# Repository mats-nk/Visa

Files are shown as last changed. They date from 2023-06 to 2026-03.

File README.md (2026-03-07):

# "Visa" Introduction

Visa is old norse for "Show" and thats what this project is about.

## First boot:
 - Activate a AP "LED_MATRIX"
 - Configure WiFi and an MQTT broker

## Second boot and thereafter:
 - Publish to MQTT broker what IP it has got
 - Other configuration is acomplished by publish to specific MQTT topics.

# `tools` folder

Here you can find some python tool for get "weather data to MQTT topics" and "MQTT topics to other MQTT topics" with transformation.

### `weather_mqtt.py` — fetches weather from Open-Meteo or wttr.in and publishes to MQTT
 - Multi-language weather descriptions (10 languages)
 - Configurable fields, units, wind direction format
 - In-place countdown between fetches
 - Script version published as MQTT topic

### `mqtt_bridge.py` — forwards MQTT topics with transforms
 - Normal 1-to-1 forwarding
 - Automatic round-robin when multiple sources share the same destination
 - Transform pipeline: round, scale, offset, suffix, prefix, template, json_field
 - Wildcard subscriptions with dynamic destination topics
 - Script version published as MQTT topic

### `setup.sh` — creates the venv, installs dependencies and runs a smoke test

# MQTT Topic Reference

All topics use the pattern `<hostname>/<suffix>`.

Default hostname is `LED_MATRIX`. Replace with your configured hostname throughout.

All values are persisted to EEPROM unless noted otherwise.

---

## Runtime topics

### `LED_MATRIX/value`
Display a message.
- Long messages (wider than display) scroll continuously.
- Short messages (fits on display) are shown statically.
- A queued message waits until the current scroll pass completes before displaying.
- Supports Swedish characters: `å ä ö Å Ä Ö`
- Supports degree symbol: `°` (UTF-8 `0xC2 0xB0`, auto-transcoded to Latin-1 `0xB0`)

```bash
# Plain text
mosquitto_pub -h <MQTT broker> -t "LED_MATRIX/value" -m "Hello World"

# Swedish characters
mosquitto_pub -h <MQTT broker> -t "LED_MATRIX/value" -m "Hej Sverige åäö"

# Temperature with degree symbol
mosquitto_pub -h <MQTT broker> -t "LED_MATRIX/value" -m "Temp: 22°C"
mosquitto_pub -h <MQTT broker> -t "LED_MATRIX/value" -m "Ute: -5°C  Inne: 21°C"

# Time and date (shell substitution)
mosquitto_pub -h <MQTT broker> -t "LED_MATRIX/value" -m "$(date +'%H:%M')"
mosquitto_pub -h <MQTT broker> -t "LED_MATRIX/value" -m "$(date +'%A %d %B')"

# Combined sensor readout
mosquitto_pub -h <MQTT broker> -t "LED_MATRIX/value" -m "$(date +'%H:%M')  Temp: 22°C  Luftfukt: 45%"

# Clear the display
mosquitto_pub -h <MQTT broker> -t "LED_MATRIX/value" -m ""
```

---

### `LED_MATRIX/speed`
Scroll step delay in milliseconds. Lower = faster scroll.

Range: `10` – `500` ms. Default: `100`

```bash
mosquitto_pub -h <MQTT broker> -t "LED_MATRIX/speed" -m "50"    # fast
mosquitto_pub -h <MQTT broker> -t "LED_MATRIX/speed" -m "100"   # default
mosquitto_pub -h <MQTT broker> -t "LED_MATRIX/speed" -m "200"   # slow
```

---

### `LED_MATRIX/intensity`
Display brightness.
Range: `0` (minimum) – `15` (maximum). Default: `5`

```bash
mosquitto_pub -h <MQTT broker> -t "LED_MATRIX/intensity" -m "0"    # minimum (nearly off)
mosquitto_pub -h <MQTT broker> -t "LED_MATRIX/intensity" -m "5"    # default
mosquitto_pub -h <MQTT broker> -t "LED_MATRIX/intensity" -m "15"   # maximum
```

---

### `LED_MATRIX/state`
Turn display on or off.

`1` = on, `0` = off. Not persisted — resets to on after reboot.

When turned back on the previous message resumes automatically.

```bash
mosquitto_pub -h <MQTT broker> -t "LED_MATRIX/state" -m "0"   # off
mosquitto_pub -h <MQTT broker> -t "LED_MATRIX/state" -m "1"   # on
```

---

### `LED_MATRIX/anim`
Animation mode for scrolling messages.

Default: `0`

| Value | Name | Description |
|---|--- |--- |
| `0` | Scroll left  | Text enters from right, exits left *(default)* |
| `1` | Scroll right | Text enters from left, exits right |
| `2` | Scroll up | Text shifts upward each tick |
| `3` | Scroll down  | Text shifts downward each tick |
| `4` | Flip LR | Static left↔right mirror, redrawn each tick |
| `5` | Flip UD | Static top↔bottom mirror, redrawn each tick |
| `6` | Rotate CW | 90° clockwise rotation applied each tick |
| `7` | Invert | All pixels toggled each tick |
| `8` | Bounce | Ping-pong: scroll left then right alternating  |
| `9` | Scroll left + invert | Scroll left with inverted pixels |
| `10`  | Blink | Whole display blinks at scroll speed |
| `11`  | Wipe in | Columns fill inward from both edges |
| `12`  | Wipe out | Columns clear outward from centre |

```bash
mosquitto_pub -h <MQTT broker> -t "LED_MATRIX/anim" -m "0"    # scroll left (default)
mosquitto_pub -h <MQTT broker> -t "LED_MATRIX/anim" -m "1"    # scroll right
mosquitto_pub -h <MQTT broker> -t "LED_MATRIX/anim" -m "8"    # bounce
mosquitto_pub -h <MQTT broker> -t "LED_MATRIX/anim" -m "10"   # blink
```

---

### `LED_MATRIX/pause`
Hold time in milliseconds after each full message pass before restarting.

`0` = no pause (continuous). Max: `30000` ms. Default: `0`

Behaviour differs by message length:
- **Long message (scrolling):** display is blank during the pause.
- **Short message (static):** message stays visible during the pause, then clears briefly before redisplaying.

```bash
mosquitto_pub -h <MQTT broker> -t "LED_MATRIX/pause" -m "0"      # continuous (default)
mosquitto_pub -h <MQTT broker> -t "LED_MATRIX/pause" -m "2000"   # 2 second pause
mosquitto_pub -h <MQTT broker> -t "LED_MATRIX/pause" -m "5000"   # 5 second pause
mosquitto_pub -h <MQTT broker> -t "LED_MATRIX/pause" -m "10000"  # 10 second pause
```

---

### `LED_MATRIX/align`
Text alignment for short messages that fit within the display width.

Has no effect on scrolling messages. Default: `0`

| Value | Alignment |
|---|---|
| `0` | Left *(default)* |
| `1` | Centre |
| `2` | Right |

```bash
mosquitto_pub -h <MQTT broker> -t "LED_MATRIX/align" -m "0"   # left (default)
mosquitto_pub -h <MQTT broker> -t "LED_MATRIX/align" -m "1"   # centre — good for time "12:45"
mosquitto_pub -h <MQTT broker> -t "LED_MATRIX/align" -m "2"   # right
```

---

## Hardware config topics

Changes to hardware config topics trigger a full matrix reinitialisation without reboot.

The display briefly shows `reconfigured!` then resumes the previous message.

### `LED_MATRIX/config/hwtype`
MAX7219 module hardware type.

Default: `3` (FC16)

| Value | Type |
|---|---|
| `0` | PAROLA_HW |
| `1` | GENERIC_HW |
| `2` | ICSTATION_HW |
| `3` | FC16_HW *(default)* |

```bash
mosquitto_pub -h <MQTT broker> -t "LED_MATRIX/config/hwtype" -m "3"   # FC16 (most common)
mosquitto_pub -h <MQTT broker> -t "LED_MATRIX/config/hwtype" -m "1"   # Generic
```

---

### `LED_MATRIX/config/numdevices`
Number of chained MAX7219 modules.

Range: `1` – `8`. Default: `4`

```bash
mosquitto_pub -h <MQTT broker> -t "LED_MATRIX/config/numdevices" -m "4"   # 4 modules
mosquitto_pub -h <MQTT broker> -t "LED_MATRIX/config/numdevices" -m "8"   # 8 modules
```

---

### `LED_MATRIX/config/clkpin`
GPIO number for SPI CLK.

Default (ESP8266 D1 Mini): `14` (D5)

```bash
mosquitto_pub -h <MQTT broker> -t "LED_MATRIX/config/clkpin" -m "14"
```

---

### `LED_MATRIX/config/datapin`
GPIO number for SPI DATA/MOSI.

Default (ESP8266 D1 Mini): `13` (D7)

```bash
mosquitto_pub -h <MQTT broker> -t "LED_MATRIX/config/datapin" -m "13"
```

---

### `LED_MATRIX/config/cspin`
GPIO number for SPI CS/SS.

Default (ESP8266 D1 Mini): `12` (D6)

```bash
mosquitto_pub -h <MQTT broker> -t "LED_MATRIX/config/cspin" -m "12"
```

---

### `LED_MATRIX/config/auxpin`
GPIO number for auxiliary output (e.g. LDR enable).

Default (ESP8266): `3`

```bash
mosquitto_pub -h <MQTT broker> -t "LED_MATRIX/config/auxpin" -m "3"
```

---

### `LED_MATRIX/config/hbledpin`
GPIO number for heartbeat LED.

Default (ESP8266): `2`

```bash
mosquitto_pub -h <MQTT broker> -t "LED_MATRIX/config/hbledpin" -m "2"
```

---

### `matrix/config/hostname`
Rename the device. **Fixed topic** — always `matrix/config/hostname` regardless of current hostname, so any device can be targeted before its hostname is known.

Max 31 characters. Takes effect immediately — device reconnects to MQTT with the new name.

```bash
mosquitto_pub -h <MQTT broker> -t "matrix/config/hostname" -m "LOBBY"
mosquitto_pub -h <MQTT broker> -t "matrix/config/hostname" -m "RECEPTION"
mosquitto_pub -h <MQTT broker> -t "matrix/config/hostname" -m "LED_MATRIX"   # reset to default
```

---

## Status topic (published by device)

### `LED_MATRIX/config/status`
Published by the device on every MQTT connect and after errors.
Includes firmware version as the first field.

```
fw=2025-03-07.1 hostname=LED_MATRIX mqtt=<MQTT broker>:1883 hwType=3 devices=8 clk=14 data=13 cs=12 aux=3 hbled=2 speed=100 intensity=5 anim=0 pause=0 align=0
```

```bash
# Subscribe to watch status
mosquitto_sub -h <MQTT broker> -t "LED_MATRIX/config/status"

# Trigger a status republish by cycling state
mosquitto_pub -h <MQTT broker> -t "LED_MATRIX/state" -m "1"
```

---

## Active/online topic (published by device)

### `LED_MATRIX/active`
Published as `online` on every MQTT connect. Used by Home Assistant as the availability topic — entities show as unavailable if the device drops off the network.

```bash
mosquitto_sub -h <MQTT broker> -t "LED_MATRIX/active"
```

---

## Practical examples

### Clock display — centred, refreshed every minute
```bash
# Set up display style once
mosquitto_pub -h <MQTT broker> -t "LED_MATRIX/align"   -m "1"     # centre
mosquitto_pub -h <MQTT broker> -t "LED_MATRIX/pause"   -m "0"     # no pause
mosquitto_pub -h <MQTT broker> -t "LED_MATRIX/anim"    -m "0"

# Then update time each minute via cron or Home Assistant automation
mosquitto_pub -h <MQTT broker> -t "LED_MATRIX/value"   -m "$(date +'%H:%M')"
```

### Temperature ticker from Home Assistant
```bash
# Long scrolling message with temperature and humidity
mosquitto_pub -h <MQTT broker> -t "LED_MATRIX/value" -m "Ute: -3°C  Inne: 21°C  Luftfukt: 42%"
mosquitto_pub -h <MQTT broker> -t "LED_MATRIX/speed" -m "80"
mosquitto_pub -h <MQTT broker> -t "LED_MATRIX/pause" -m "3000"
```

### Night mode — dim and slow
```bash
mosquitto_pub -h <MQTT broker> -t "LED_MATRIX/intensity" -m "1"
mosquitto_pub -h <MQTT broker> -t "LED_MATRIX/speed"     -m "150"
```

### Day mode — bright and fast
```bash
mosquitto_pub -h <MQTT broker> -t "LED_MATRIX/intensity" -m "10"
mosquitto_pub -h <MQTT broker> -t "LED_MATRIX/speed"     -m "60"
```

### Turn off at bedtime, on at wake-up
```bash
mosquitto_pub -h <MQTT broker> -t "LED_MATRIX/state" -m "0"   # off — previous message saved
mosquitto_pub -h <MQTT broker> -t "LED_MATRIX/state" -m "1"   # on  — previous message resumes
```

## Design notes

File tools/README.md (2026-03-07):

# Weather MQTT – Documentation

A pair of Python scripts that fetch weather data and forward MQTT topics, driven entirely by YAML configuration files.

---

## Table of Contents

1. [Quick Start](#quick-start)
2. [weather_mqtt.py](#weather_mqttpy)
   - [Requirements](#requirements)
   - [Installation](#installation)
   - [Command-line Usage](#command-line-usage)
   - [Configuration Reference – config.yaml](#configuration-reference--configyaml)
   - [MQTT Topics Published](#mqtt-topics-published)
   - [Weather Fields](#weather-fields)
   - [Units](#units)
   - [Wind Direction Formats](#wind-direction-formats)
   - [Language Support](#language-support)
   - [Running as a Service](#running-as-a-service-weather_mqtt)
3. [mqtt_bridge.py](#mqtt_bridgepy)
   - [Requirements](#requirements-1)
   - [Command-line Usage](#command-line-usage-1)
   - [Configuration Reference – mqtt_bridge_config.yaml](#configuration-reference--mqtt_bridge_configyaml)
   - [Mapping Types](#mapping-types)
   - [Transform Pipeline](#transform-pipeline)
   - [Round-Robin Rotation](#round-robin-rotation)
   - [Wildcard Topics](#wildcard-topics)
   - [Running as a Service](#running-as-a-service-mqtt_bridge)
4. [YAML Tips](#yaml-tips)
5. [Version Numbering](#version-numbering)

---

## Quick Start

```bash
# 1. Create virtual environment and install dependencies
chmod +x setup.sh
./setup.sh

# 2. Edit config.yaml with your location and broker address
# 3. Run
source .venv/bin/activate
python weather_mqtt.py
```

---

## weather_mqtt.py

Fetches current weather conditions (and optionally a short-term forecast) from either **Open-Meteo** or **wttr.in**, and publishes the selected fields to an MQTT broker at a configurable interval.

### Requirements

Python 3.8+ and three packages:

```bash
pip install paho-mqtt requests pyyaml
```

### Installation

```bash
./setup.sh          # creates .venv, installs packages, runs a smoke test
```

Or manually:

```bash
python -m venv .venv
source .venv/bin/activate
pip install paho-mqtt requests pyyaml
```

### Command-line Usage

```
python weather_mqtt.py [options]

Options:
  --config FILE   Path to YAML config file  (default: config.yaml)
  --once          Fetch once and exit – ignores the interval setting
  --dry-run       Print payloads to stdout without connecting to MQTT
```

Examples:

```bash
# Test without touching the broker
python weather_mqtt.py --dry-run --once

# Use a custom config file
python weather_mqtt.py --config my_weather.yaml

# Run continuously (default)
python weather_mqtt.py
```

---

### Configuration Reference – config.yaml

#### `mqtt` section

| Key | Default | Description |
|-----|---|---|
| `broker` | `localhost` | Hostname or IP of your MQTT broker |
| `port` | `1883` | Port – use `8883` for TLS |
| `username` | `""` | Leave empty if no authentication required |
| `password` | `""` | Leave empty if no authentication required |
| `client_id` | `weather_publisher` | MQTT client identifier |
| `tls` | `false` | Enable TLS/SSL |
| `ca_cert` | *(unset)* | Path to CA certificate file (TLS only) |
| `base_topic` | `weather` | Root topic prefix |
| `topic_per_field` | `true` | `true` = one sub-topic per field; `false` = single JSON payload |
| `json_topic` | `weather/all` | Topic used when `topic_per_field` is `false` |
| `retain` | `true` | Set the MQTT retain flag on published messages |
| `qos` | `1` | MQTT QoS level – `0`, `1`, or `2` |

#### `weather` section

| Key | Default | Description |
|-----|---|---|
| `service` | `open-meteo` | Weather data source: `open-meteo` or `wttr.in` |
| `latitude` | — | Decimal degrees latitude |
| `longitude` | — | Decimal degrees longitude |
| `location_name` | — | Human-readable name – used by wttr.in as the lookup string |
| `interval` | `900` | Seconds between fetches (900 = every 15 minutes) |
| `language` | `en` | Language for weather descriptions – see [Language Support](#language-support) |

#### `weather.units` section

| Key | Default | Options | Description |
|-----|---|---|---|
| `temperature` | `celsius` | `celsius` / `fahrenheit` | Temperature unit |
| `wind_speed` | `ms` | `ms` / `kmh` / `mph` / `knots` | Wind speed unit |
| `wind_direction` | `16-compass` | `degrees` / `16-compass` / `12-compass` | Wind direction format |
| `precipitation` | `mm` | `mm` / `inch` | Precipitation unit |
| `timezone` | `auto` | Any IANA tz string | Open-Meteo only – `auto` uses the location's timezone |

#### `weather.fields` section

Each field can be set to `true` (publish) or `false` (skip).

| Field | Description | Service |
|---|---|---|
| `temperature` | Current temperature | Both |
| `feels_like` | Apparent / feels-like temperature | Both |
| `humidity` | Relative humidity (%) | Both |
| `precipitation` | Precipitation last hour | Both |
| `rain` | Rain component | open-meteo |
| `wind_speed` | Wind speed | Both |
| `wind_direction` | Wind direction (format per `units.wind_direction`) | Both |
| `wind_gusts` | Wind gust speed | Both |
| `cloud_cover` | Cloud cover (%) | Both |
| `visibility` | Visibility (metres) | open-meteo |
| `surface_pressure` | Atmospheric pressure (hPa) | Both |
| `weather_code` | WMO numeric weather code | Both |
| `weather_description` | Human-readable description of the weather code | Both |
| `is_day` | `1` = daytime, `0` = night | open-meteo |
| `forecast_enabled` | Enable hourly forecast | open-meteo |
| `forecast_hours` | How many hours of forecast to include | open-meteo |
| `forecast_temperature_max` | Max temperature per forecast hour | open-meteo |
| `forecast_temperature_min` | Min temperature per forecast hour | open-meteo |
| `forecast_precipitation_sum` | Precipitation sum per forecast hour | open-meteo |
| `forecast_wind_speed_max` | Max wind speed per forecast hour | open-meteo |
| `forecast_weather_code` | Weather code per forecast hour | open-meteo |

#### `logging` section

| Key | Default | Description |
|-----|---|---|
| `level` | `INFO` | Log level: `DEBUG` / `INFO` / `WARNING` / `ERROR` |
| `log_to_file` | `false` | Also write log output to a file |
| `log_file` | `weather_mqtt.log` | Log file path (only used when `log_to_file: true`) |

---

### MQTT Topics Published

With `base_topic: weather` and `topic_per_field: true`:

```
weather/version               → 2026-03-07.1
weather/temperature           → 21.4
weather/feels_like            → 19.8
weather/humidity              → 62
weather/wind_speed            → 4.2
weather/wind_direction        → WSW
weather/wind_gusts            → 7.1
weather/precipitation         → 0.0
weather/cloud_cover           → 45
weather/surface_pressure      → 1013.2
weather/weather_code          → 2
weather/weather_description   → Halvklart
weather/timestamp             → 2026-03-07T20:33:00+00:00
weather/source                → open-meteo
```

With `topic_per_field: false`, all fields are published as a single JSON object to `weather/all`.

---

### Weather Fields

All numeric values are plain strings (no unit suffix) so downstream consumers can parse them as numbers directly. Use `mqtt_bridge.py` with a `suffix` transform if you need a unit appended.

---

### Units

**Temperature:** `celsius` or `fahrenheit`

**Wind speed:**

| Value | Unit |
|---|---|
| `ms` | metres per second (default) |
| `kmh` | kilometres per hour |
| `mph` | miles per hour |
| `knots` | knots |

**Precipitation:** `mm` or `inch`

---

### Wind Direction Formats

| Value | Example output | Sector size |
|---|---|---|
| `degrees` | `247` | raw 0–360° float |
| `16-compass` | `WSW` | 22.5° per sector |
| `12-compass` | `W` | 30° per sector |

---

### Language Support

Set `language` under the `weather` key. Descriptions fall back to English for any untranslated code.

| Code | Language |
|---|---|
| `en` | English |
| `sv` | Swedish |
| `de` | German |
| `fr` | French |
| `nl` | Dutch |
| `es` | Spanish |
| `no` | Norwegian |
| `fi` | Finnish |
| `da` | Danish |
| `pl` | Polish |

To add a language, add a new key to `_WMO_TRANSLATIONS` in `weather_mqtt.py`. The key is the ISO 639-1 code in lower-case.

---

### Running as a Service (weather_mqtt)

```ini
# /etc/systemd/system/weather_mqtt.service
[Unit]
Description=Weather MQTT Publisher
After=network-online.target

[Service]
ExecStart=/opt/weather/. .venv/bin/activate && python weather_mqtt.py
WorkingDirectory=/opt/weather
Restart=on-failure
RestartSec=30

[Install]
WantedBy=multi-user.target
```

```bash
sudo systemctl enable --now weather_mqtt
```

---

## mqtt_bridge.py

Subscribes to MQTT topics on a source broker and republishes them to a destination broker (which can be the same broker). Supports value transforms, wildcard subscriptions, and automatic round-robin rotation when multiple sources share the same destination topic.

### Requirements

Python 3.8+ and two packages:

```bash
pip install paho-mqtt pyyaml
```

### Command-line Usage

```
python mqtt_bridge.py [options]

Options:
  --config FILE   Path to YAML config file  (default: mqtt_bridge_config.yaml)
  --dry-run       Log all forwards without publishing to destination
  --list          Print active mappings and exit
```

Examples:

```bash
# See all active mappings
python mqtt_bridge.py --list

# Test without publishing anything
python mqtt_bridge.py --dry-run

# Use a custom config
python mqtt_bridge.py --config home_bridge.yaml
```

Sample `--list` output:

```
mqtt_bridge.py  v2026-03-07.1
────────────────────────────────────────────────────────────
  Active mappings  (2):
    weather/temperature             →  house/outside/temperature
    weather/humidity                →  house/outside/humidity

  Active round-robin group  (1):
    → LED_MATRIX/value
      [1] weather/temperature    [round:0 → suffix: °C → prefix:Ute:  ]
      [2] weather/wind_speed     [round:1 → suffix: m/s → prefix:Blåst:  ]
      [3] weather/humidity       [round:2 → suffix: % → prefix:Fukt:  ]

  Disabled mappings  (3):
    ...
```

---

### Configuration Reference – mqtt_bridge_config.yaml

#### `source` section

| Key | Default | Description |
|-----|---|---|
| `broker` | `localhost` | Source broker hostname or IP |
| `port` | `1883` | Source broker port |
| `username` | `""` | Authentication username |
| `password` | `""` | Authentication password |
| `client_id` | `mqtt_bridge_source` | MQTT client identifier |
| `tls` | `false` | Enable TLS |
| `ca_cert` | *(unset)* | CA certificate path (TLS only) |

#### `destination` section

Same keys as `source`, plus:

| Key | Default | Description |
|-----|---|---|
| `client_id` | `mqtt_bridge_destination` | MQTT client identifier |
| `retain` | `true` | Global retain flag for published messages |
| `qos` | `1` | Global QoS for published messages |

> Source and destination can point to the same broker — topic names must then differ to avoid loops.

#### `bridge` section

| Key | Default | Description |
|-----|---|---|
| `heartbeat_interval` | `60` | Seconds between heartbeats and round-robin advances. Set to `0` to disable. |
| `version_topic` | `bridge/version` | Topic where the script version is published on startup and each heartbeat |

#### `logging` section

| Key | Default | Description |
|-----|---|---|
| `level` | `INFO` | `DEBUG` / `INFO` / `WARNING` / `ERROR` |
| `log_to_file` | `false` | Write log output to a file |
| `log_file` | `mqtt_bridge.log` | Log file path |

---

### Mapping Types

#### Normal mapping

Forwards every received message immediately.

```yaml
mappings:
  - from: "weather/temperature"
    to:   "house/outside/temperature"
    enabled: true
```

| Key | Default | Description |
|-----|---|---|
| `from` | — | Source topic to subscribe to |
| `to` | — | Destination topic to publish to |
| `enabled` | `true` | Set `false` to disable without deleting |
| `retain` | *(global)* | Override global retain for this mapping |
| `qos` | *(global)* | Override global QoS for this mapping |
| `transform` | *(none)* | Single transform string or list of steps |
| `round_robin` | `false` | Force round-robin even with a unique destination |

#### Round-robin mapping

When two or more enabled mappings share the same `to` topic, they are **automatically grouped** into a round-robin. On each heartbeat, only one source is published to the shared destination, rotating through the list in order.

```yaml
mappings:
  - from: "weather/temperature"
    to:   "LED_MATRIX/value"
    transform:
      - "round:0"
      - "suffix: °C"
      - 'prefix:Ute:  '

  - from: "weather/wind_speed"
    to:   "LED_MATRIX/value"
    transform:
      - "round:1"
      - "suffix: m/s"
      - 'prefix:Blåst:  '

  - from: "weather/humidity"
    to:   "LED_MATRIX/value"
    transform:
      - "round:0"
      - "suffix: %"
      - 'prefix:Fukt:  '
```

Rotation sequence per heartbeat:

```
Heartbeat 1 → weather/temperature → LED_MATRIX/value : Ute:  21 °C
Heartbeat 2 → weather/wind_speed  → LED_MATRIX/value : Blåst:  3.2 m/s
Heartbeat 3 → weather/humidity    → LED_MATRIX/value : Fukt:  62 %
Heartbeat 4 → weather/temperature → LED_MATRIX/value : Ute:  21 °C  (wraps)
```

> The `heartbeat_interval` in the `bridge` section controls how quickly the rotation advances.

---

### Transform Pipeline

A `transform` can be a **single string** or a **YAML list** applied left-to-right:

```yaml
# Single step
transform: "round:1"

# Pipeline – output of each step feeds into the next
transform:
  - "round:1"
  - "suffix: °C"
  - 'prefix:Temp:  '
```

#### Available transforms

| Transform | Example | Input | Output |
|---|---|---|---|
| `passthrough` | `passthrough` | `21.357` | `21.357` |
| `round:N` | `round:1` | `21.357` | `21.4` |
| `scale:F` | `scale:0.1` | `213.57` | `21.357` |
| `offset:N` | `offset:-273.15` | `294.15` | `21.0` |
| `upper` | `upper` | `partly cloudy` | `PARTLY CLOUDY` |
| `lower` | `lower` | `PARTLY CLOUDY` | `partly cloudy` |
| `suffix:STR` | `suffix: °C` | `21.4` | `21.4 °C` |
| `prefix:STR` | `'prefix:Ute:  '` | `21.4` | `Ute:  21.4` |
| `json_field:KEY` | `json_field:temperature` | `{"temperature":21.4}` | `21.4` |
| `template:STR` | `template:Temp is {value}` | `21.4` | `Temp is 21.4` |

> **YAML tip:** When your `prefix` or `suffix` ends with spaces, always use **single quotes** to prevent YAML from stripping trailing whitespace:
> ```yaml
> transform: 'prefix:Ute:  '   # ✓ spaces preserved
> transform: "prefix:Ute:  "   # ✗ trailing spaces may be stripped
> ```

---

### Wildcard Topics

MQTT wildcards `+` (single level) and `#` (multi-level) are supported in `from`.
The matched topic segments can be used in the `to` pattern:

| Placeholder | Meaning |
|---|---|
| `{topic}` | Full source topic string |
| `{0}`, `{1}`, … | Individual topic levels (0-indexed) |

```yaml
# Forward every sensor's temperature to an archive topic
- from: "sensors/+/temperature"
  to:   "archive/{1}/temp"
  # sensors/kitchen/temperature → archive/kitchen/temp
  # sensors/garden/temperature  → archive/garden/temp

# Archive everything under weather/
- from: "weather/#"
  to:   "archive/{1}"
  # weather/temperature → archive/temperature
  # weather/humidity    → archive/humidity
```

---

### Running as a Service (mqtt_bridge)

```ini
# /etc/systemd/system/mqtt_bridge.service
[Unit]
Description=MQTT Topic Bridge
After=network-online.target

[Service]
ExecStart=/opt/weather/.venv/bin/python /opt/weather/mqtt_bridge.py
WorkingDirectory=/opt/weather
Restart=on-failure
RestartSec=15

[Install]
WantedBy=multi-user.target
```

```bash
sudo systemctl enable --now mqtt_bridge
```

---

## YAML Tips

**Indentation** — YAML uses spaces, never tabs. All items in the same list must align exactly:

```yaml
# ✓ correct – all dashes at the same column
transform:
  - "round:1"
  - "suffix: °C"

# ✗ wrong – mixed indentation causes a parser error
transform:
      - "round:1"
     - "suffix: °C"
```

**One key per entry** — duplicate keys are silently overwritten:

```yaml
# ✗ wrong – second transform silently replaces the first
- from: "weather/temperature"
  transform: "round:1"
  transform: "suffix: °C"

# ✓ correct – use a list
- from: "weather/temperature"
  transform:
    - "round:1"
    - "suffix: °C"
```

**Trailing spaces** — always use single quotes when your value ends with spaces:

```yaml
transform: 'prefix:Ute:  '    # ✓ spaces kept
transform: "prefix:Ute:  "    # ✗ spaces may be stripped
```

**`mappings:` must be a top-level key** — do not nest it inside `bridge:` or any other section:

```yaml
bridge:
  heartbeat_interval: 10

mappings:           # ✓ top-level
  - from: "..."
```

---

## Version Numbering

Both scripts use the format `YYYY-MM-DD.N` where `N` is a sequence number starting at 1 for that date.

```python
__VERSION__ = "2026-03-07.1"
```

The version is published as an MQTT topic on startup (and on every heartbeat for `mqtt_bridge.py`):

| Script | Topic |
|---|---|
| `weather_mqtt.py` | `{base_topic}/version` e.g. `weather/version` |
| `mqtt_bridge.py` | configured by `bridge.version_topic` e.g. `bridge/version` |

To bump the version after making changes, edit the `__VERSION__` line near the top of the relevant script.

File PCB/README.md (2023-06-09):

# MAX7219 4x8x8 matrix module

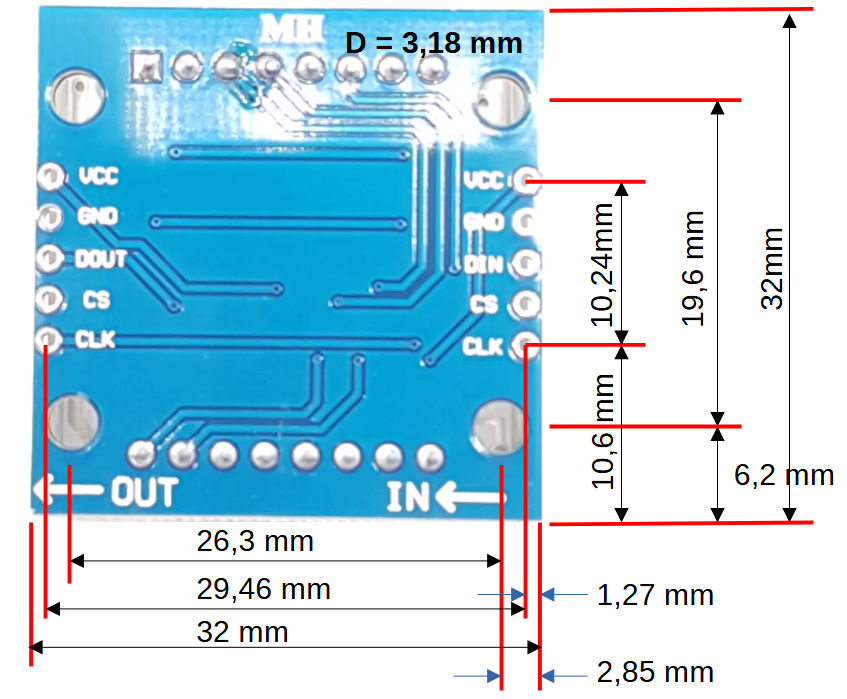
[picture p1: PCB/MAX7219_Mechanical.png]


# ESP8266 

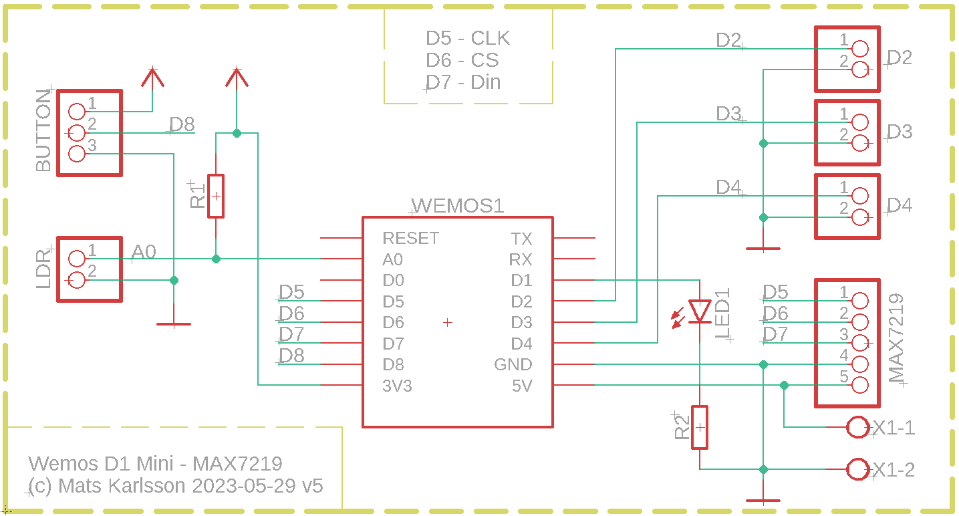
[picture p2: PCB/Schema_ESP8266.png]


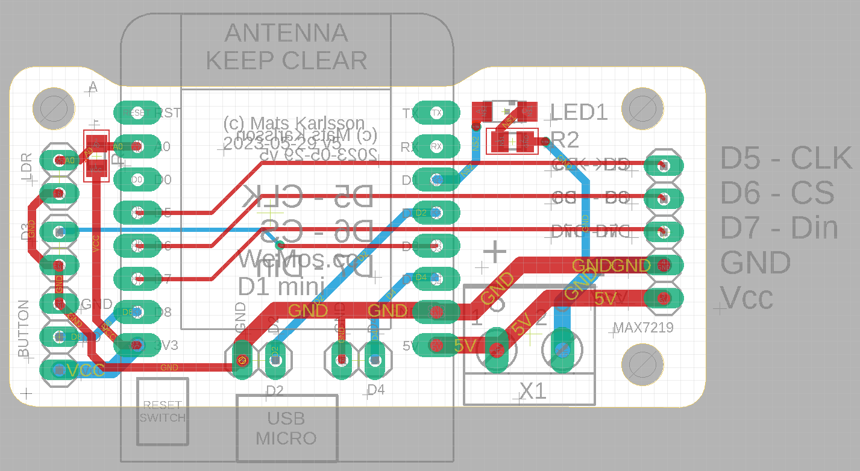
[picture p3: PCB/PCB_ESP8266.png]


# ESP32

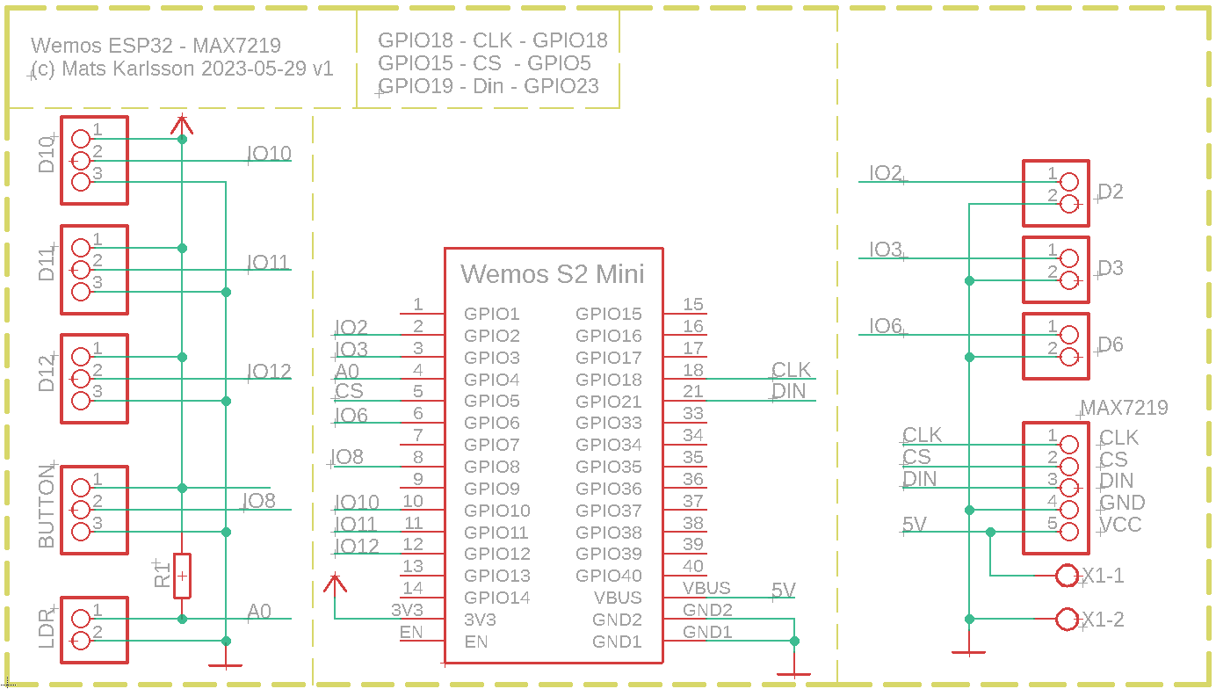
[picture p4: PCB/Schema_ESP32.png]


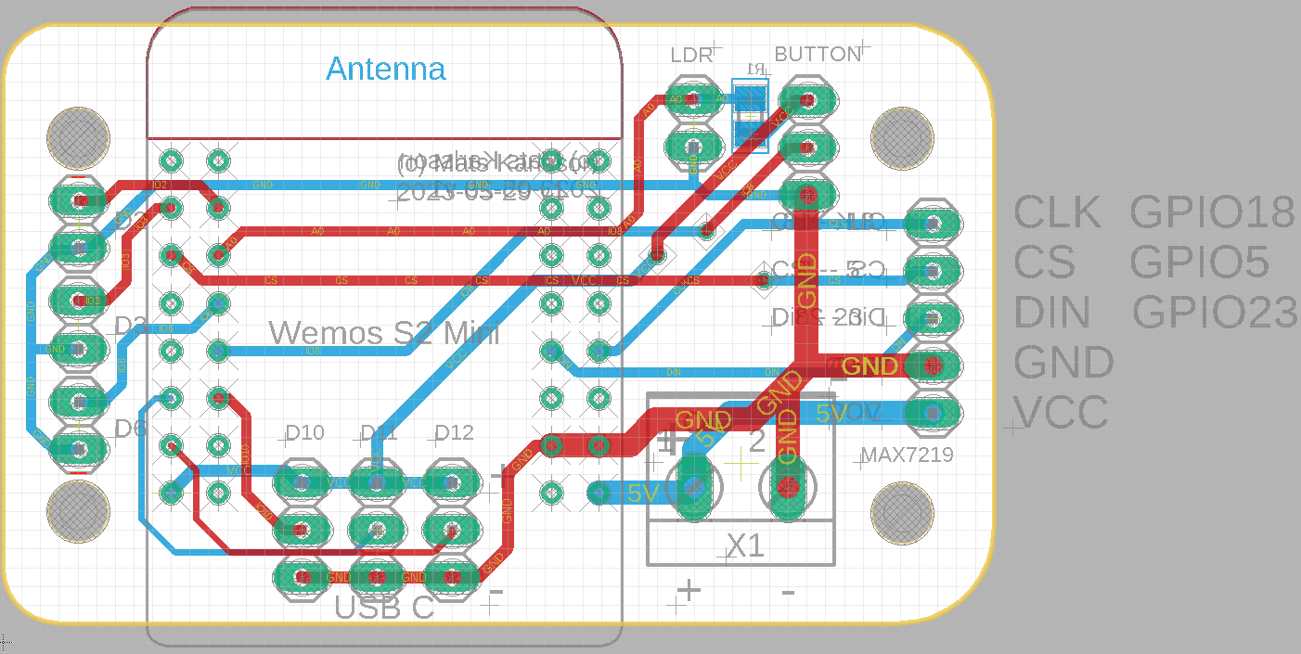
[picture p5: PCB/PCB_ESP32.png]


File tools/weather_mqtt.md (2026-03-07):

# weather_mqtt – Weather → MQTT Publisher

Fetch current weather (and optionally a short-term forecast) from
**Open-Meteo** or **wttr.in** and publish the selected fields to an MQTT
broker. Everything is driven by a single `config.yaml` file.

---

## Files

| File | Purpose |
|---|---|
| `weather_mqtt.py` | Main script |
| `config.yaml` | All configuration (edit this) |

---

## Requirements

Python 3.8 + and three pip packages:

```bash
pip install paho-mqtt requests pyyaml
```

---

## Quick start

1. **Edit `config.yaml`** – set your broker address, location, and the fields
   you want.
2. **Test without MQTT:**
   ```bash
   python weather_mqtt.py --dry-run --once
   ```
3. **Run once for real:**
   ```bash
   python weather_mqtt.py --once
   ```
4. **Run continuously** (publishes every `interval` seconds):
   ```bash
   python weather_mqtt.py
   ```

---

## Key configuration options

### MQTT

```yaml
mqtt:
  broker: "192.168.1.10"
  port: 1883
  username: "user"
  password: "secret"
  base_topic: "home/weather"
  topic_per_field: true   # each field → own sub-topic
  retain: true
  qos: 1
```

`topic_per_field: true` → publishes e.g.
- `home/weather/temperature` → `21.4`
- `home/weather/humidity` → `62`
- `home/weather/weather_description` → `Partly cloudy`

`topic_per_field: false` → publishes one JSON payload to `json_topic`.

### Weather service

```yaml
weather:
  service: "open-meteo"   # or "wttr.in"
  latitude: 59.3293
  longitude: 18.0686
  location_name: "Stockholm"   # used by wttr.in
  interval: 300                # seconds between fetches
```

### Units

```yaml
  units:
    temperature: "celsius"    # celsius | fahrenheit
    wind_speed: "kmh"         # kmh | mph | ms | knots
    precipitation: "mm"       # mm | inch
    timezone: "auto"          # open-meteo only
```

### Fields

```yaml
  fields:
    temperature: true
    feels_like: true
    humidity: true
    wind_speed: true
    wind_direction: true
    wind_gusts: true
    cloud_cover: true
    surface_pressure: true
    precipitation: true
    weather_code: true
    weather_description: true   # human-readable WMO description
    visibility: false
    is_day: false
    forecast_enabled: false     # open-meteo only
    forecast_hours: 24
```

---

## Running as a service (systemd)

```ini
# /etc/systemd/system/weather_mqtt.service
[Unit]
Description=Weather MQTT Publisher
After=network-online.target

[Service]
ExecStart=/usr/bin/python3 /opt/weather_mqtt/weather_mqtt.py
WorkingDirectory=/opt/weather_mqtt
Restart=on-failure
RestartSec=30

[Install]
WantedBy=multi-user.target
```

```bash
sudo systemctl enable --now weather_mqtt
```

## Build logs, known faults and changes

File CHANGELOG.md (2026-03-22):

# Changelog

All notable changes to Visa are documented here.
Format follows [Keep a Changelog](https://keepachangelog.com/en/1.0.0/).

---

## [2025-03-07.4] — 2025-03-07

### Added
- Home Assistant: IP address published as retained MQTT topic `<hostname>/ip` and exposed as a diagnostic sensor entity
- Home Assistant: Firmware version published as retained MQTT topic `<hostname>/firmware` and exposed as a diagnostic sensor entity
- Home Assistant: `stat_t` (state topic) added to Speed, Pause, Animation and Alignment discovery payloads — HA sliders and selects now reflect real device state immediately after connect
- Home Assistant: Device card now shows firmware version via the `sw` field in the discovery device block
- `publishCurrentState()` — publishes all current config values (on/off, intensity, speed, pause, anim, align, IP, firmware) with `retain=true` on every MQTT connect
- Shared `animNames[]` and `alignNames[]` string tables used by both MQTT callback and HA discovery — no duplication

### Changed
- Home Assistant Animation select now shows human-readable option names (`Scroll Left`, `Bounce`, `Blink` etc.) instead of raw integers
- Home Assistant Alignment select now shows human-readable option names (`Left`, `Center`, `Right`) instead of raw integers
- `MQTTcallback()` accepts both human-readable name strings (from HA) and numeric strings (direct MQTT) for `anim` and `align` topics — fully backwards compatible

---

## [2025-03-07.3] — 2025-03-07

### Added
- Home Assistant MQTT Discovery: auto-creates six entities (Message text, Display light, Scroll Speed number, Pause number, Animation select, Alignment select)
- Availability topic `<hostname>/active` — HA entities show unavailable when device is offline
- `pauseMs` config field — hold display for configurable duration after each message pass
- `alignText` config field — left / centre / right alignment for short static messages
- 13 animation modes: Scroll Left/Right/Up/Down, Flip LR/UD, Rotate CW, Invert, Bounce, Scroll Left Inv, Blink, Wipe In, Wipe Out
- `ANIM_BOUNCE` ping-pong scroll mode
- `ANIM_BLINK` whole-display blink mode
- `ANIM_WIPE_IN` / `ANIM_WIPE_OUT` column wipe modes
- `displayStatic()` renderer for short messages with alignment support
- `messagePixelWidth()` helper for short/long message detection
- Config topics for auxiliary pin (`config/auxpin`) and heartbeat LED pin (`config/hbledpin`)
- Fixed rename topic `matrix/config/hostname` — any device can be renamed before its hostname is known

### Changed
- Scroll state machine extended with `S_PASS_END` state to support end-of-pass pause
- `scrollReset` flag added for clean state machine restart when switching static↔scroll

---

## [2025-03-07.1] — 2025-03-07

### Added
- Initial release
- ESP8266 / ESP32 / ESP32-S2 / ESP32-C3 multi-architecture support
- WiFiManager captive portal for first-boot WiFi + MQTT broker provisioning
- ArduinoOTA with mDNS — flash over WiFi via `<hostname>.local`
- MQTT-driven message display with UTF-8 → Latin-1 transcoding
- Swedish character support: `å ä ö Å Ä Ö` and degree symbol `°`
- Scroll left animation via MD_MAX72XX transform callbacks
- EEPROM persistence for all config fields
- Per-architecture default SPI pin definitions
- `DEBUG` and `LED_HEARTBEAT` compile-time flags
- Config status topic `<hostname>/config/status` published on every connect
- Hardware reconfigure via MQTT without reboot (hwtype, numdevices, clkpin, datapin, cspin)
- `FW_VERSION` constant published in status topic

---

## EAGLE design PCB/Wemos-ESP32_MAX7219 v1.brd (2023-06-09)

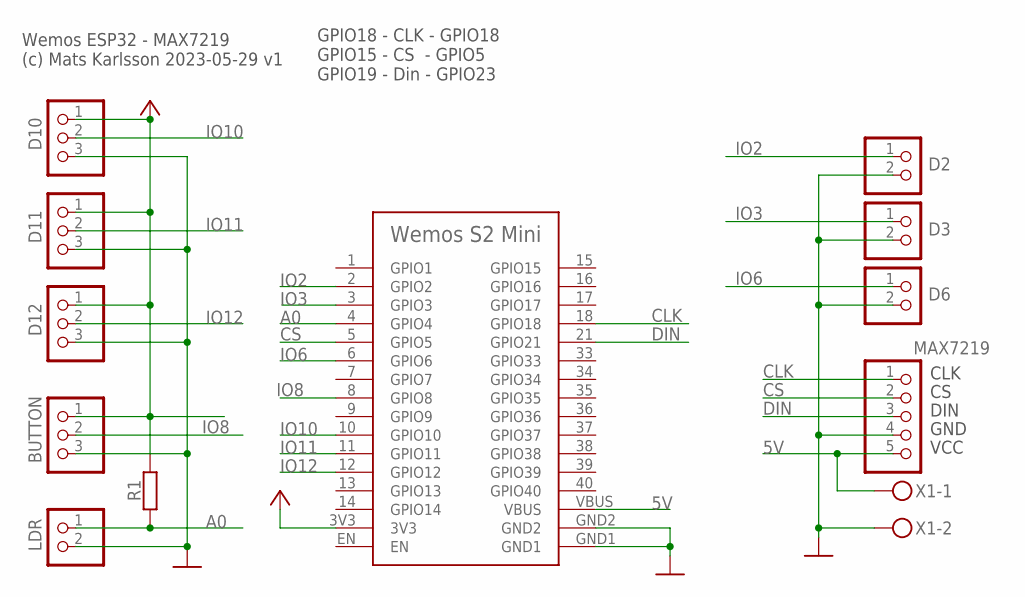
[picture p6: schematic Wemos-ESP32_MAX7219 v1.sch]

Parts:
BUTTON: PINHD-1X3; 1X03
D2, D3, D6: PINHD-1X2; 1X02
D10, D11, D12: PINHD-1X3; 1X03
LDR: PINHD-1X2; 1X02
MAX7219: PINHD-1X5; 1X05
R1: R-EU_M0805; M0805
U$1: WEMOS_S2_MINI
X1: W237-102

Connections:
5V: MAX7219.5, U$1.VBUS, X1.1
A0: LDR.1, R1.2, U$1.4 (GPIO4)
CLK: MAX7219.1, U$1.18 (GPIO18)
CS: MAX7219.2, U$1.5 (GPIO5)
DIN: MAX7219.3, U$1.21 (GPIO21)
GND: BUTTON.3, D2.2, D3.2, D6.2, D10.3, D11.3, D12.3, LDR.2, MAX7219.4, U$1.GND1, U$1.GND2, X1.2
IO2: D2.1, U$1.2 (GPIO2)
IO3: D3.1, U$1.3 (GPIO3)
IO6: D6.1, U$1.6 (GPIO6)
IO8: BUTTON.2, U$1.8 (GPIO8)
IO10: D10.2, U$1.10 (GPIO10)
IO11: D11.2, U$1.11 (GPIO11)
IO12: D12.2, U$1.12 (GPIO12)
VCC: BUTTON.1, D10.1, D11.1, D12.1, R1.1, U$1.3V3

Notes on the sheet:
Wemos ESP32 - MAX7219 (c) Mats Karlsson 2023-05-29 v1
GPIO18 - CLK - GPIO18 GPIO15 - CS - GPIO5 GPIO19 - Din - GPIO23
CLK
DIN
GND
VCC

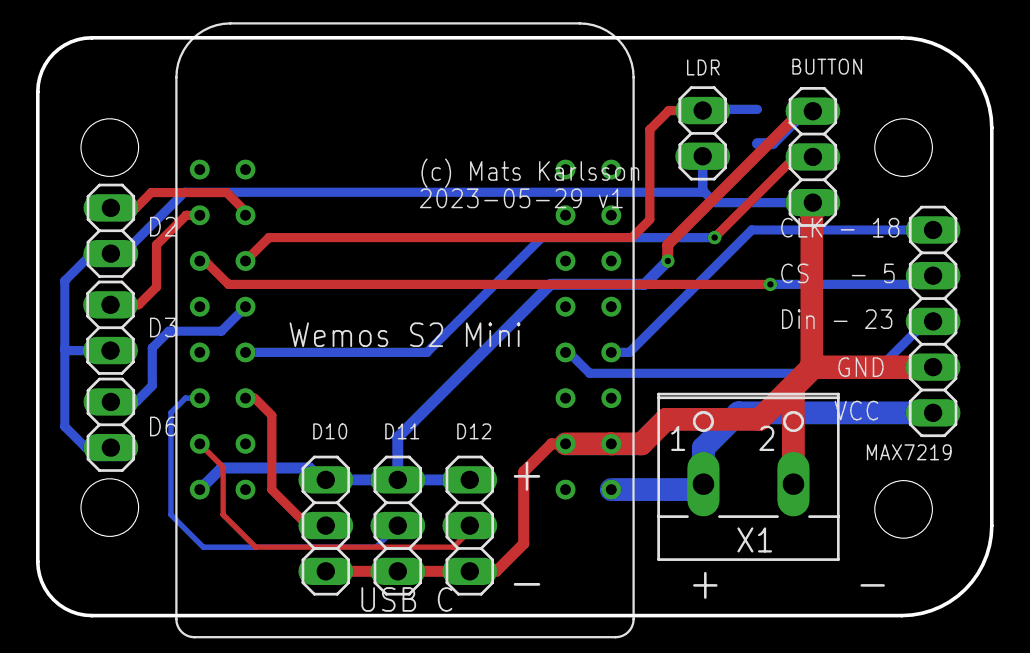
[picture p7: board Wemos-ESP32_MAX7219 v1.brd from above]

Board: 2 copper layers, 53.0 x 32.1 mm, 12 parts (1 on the bottom side), 14 nets.

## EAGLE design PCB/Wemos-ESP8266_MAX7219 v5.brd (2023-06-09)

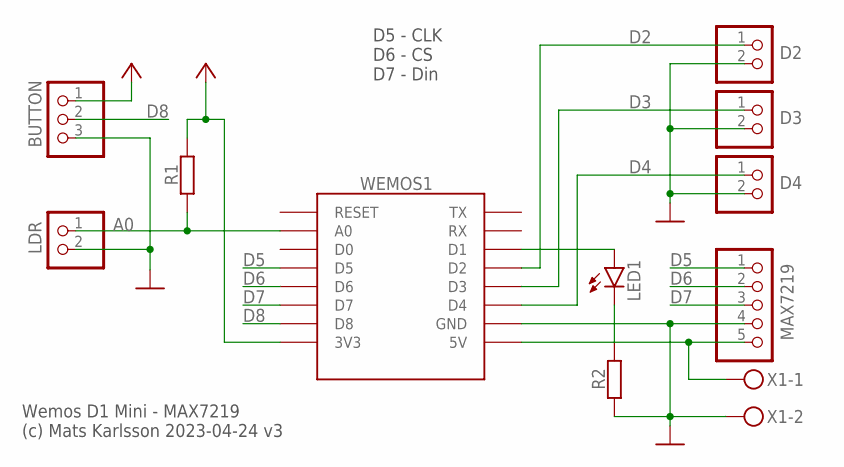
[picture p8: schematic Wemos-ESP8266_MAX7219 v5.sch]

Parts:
BUTTON: PINHD-1X3; 1X03
D2, D3, D4: PINHD-1X2; 1X02
LDR: PINHD-1X2; 1X02
LED1: LEDCHIPLED_1206; CHIPLED_1206
MAX7219: PINHD-1X5; 1X05
R1, R2: R-EU_M0805; M0805
WEMOS1: WEMOS-D1-MINI
X1: W237-102

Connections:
5V: MAX7219.5, WEMOS1.5V, X1.1
A0: LDR.1, R1.2, WEMOS1.A0
D2: D2.1, WEMOS1.D2
D3: D3.1, WEMOS1.D3
D4: D4.1, WEMOS1.D4
D5: MAX7219.1, WEMOS1.D5
D6: MAX7219.2, WEMOS1.D6
D7: MAX7219.3, WEMOS1.D7
D8: BUTTON.2, WEMOS1.D8
GND: BUTTON.3, D2.2, D3.2, D4.2, LDR.2, MAX7219.4, R2.2, WEMOS1.GND, X1.2
unnamed: LED1.C, R2.1
unnamed: LED1.A, WEMOS1.D1
VCC: BUTTON.1, R1.1, WEMOS1.3V3

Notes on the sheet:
Wemos D1 Mini - MAX7219 (c) Mats Karlsson 2023-04-24 v3
D5 - CLK D6 - CS D7 - Din

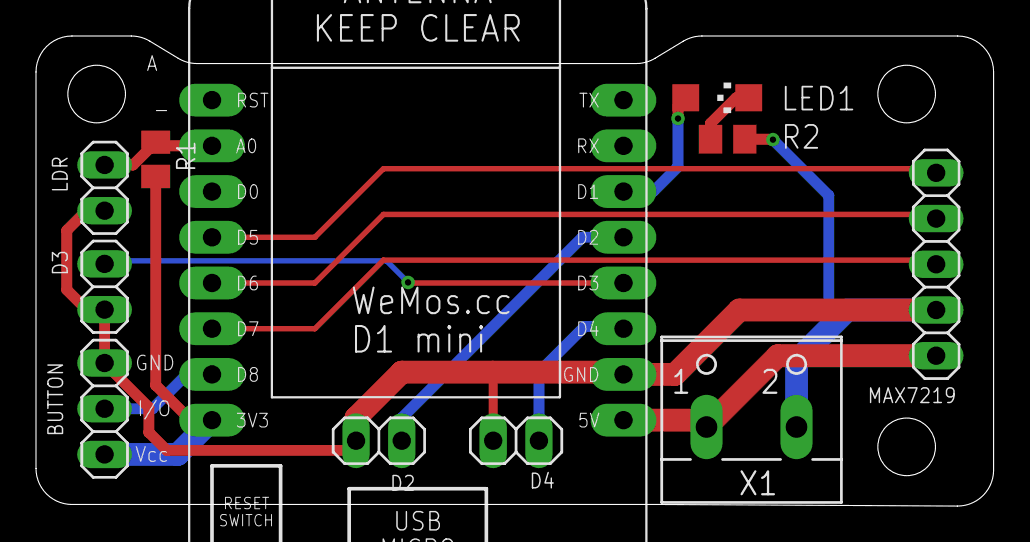
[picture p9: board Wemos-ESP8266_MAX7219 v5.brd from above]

Board: 2 copper layers, 53.2 x 26.1 mm, 11 parts (0 on the bottom side), 13 nets.

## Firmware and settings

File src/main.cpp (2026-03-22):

#include <ArduinoOTA.h>

// WiFi header differs between architectures
#if defined(ARDUINO_ARCH_ESP8266)
  #include <ESP8266WiFi.h>
#elif defined(ARDUINO_ARCH_ESP32)
  #include <WiFi.h>
#else
  #error "Unsupported platform – please add a WiFi include for your target."
#endif
#include <PubSubClient.h>
#include <WiFiManager.h>   // https://github.com/tzapu/WiFiManager
#include <MD_MAX72xx.h>
#include <SPI.h>
#include <EEPROM.h>

// ─── Firmware Version ────────────────────────────────────────────────────────
// Format: YYYY-MM-DD.N  where N is a sequential build number for that date.
#define FW_VERSION "2025-03-07.3"
#define PRINT_CALLBACK  0
#define DEBUG           0
#define LED_HEARTBEAT   0

#if DEBUG
  #define PRINT(s, v)  { Serial.print(F(s)); Serial.print(v); }
  #define PRINTS(s)    { Serial.print(F(s)); }
#else
  #define PRINT(s, v)
  #define PRINTS(s)
#endif

#if LED_HEARTBEAT
  #define HB_LED_TIME  500
#endif

// ─── EEPROM Layout ───────────────────────────────────────────────────────────
// We store a config struct at address 0.
// Magic bytes guard against reading garbage on first boot.
#define EEPROM_SIZE   sizeof(MatrixConfig)
#define EEPROM_MAGIC  0xA5

struct MatrixConfig {
  uint8_t  magic;          // 0xA5 = valid
  uint8_t  hwType;         // MD_MAX72XX::moduleType_t cast to uint8_t
  uint8_t  numDevices;     // number of chained MAX7219 modules (1–8)
  uint8_t  clkPin;         // GPIO number for CLK
  uint8_t  dataPin;        // GPIO number for DATA / MOSI
  uint8_t  csPin;          // GPIO number for CS / SS
  uint8_t  auxPin;         // GPIO number for auxiliary output (e.g. LDR enable)
  uint8_t  hbLedPin;       // GPIO number for heartbeat LED
  uint16_t scrollDelay;    // ms between scroll steps
  uint8_t  intensity;      // 0–15
  uint8_t  animMode;       // animation mode — see ANIM_* constants
  uint16_t pauseMs;        // ms to hold display after each full message pass (0 = no pause)
  uint8_t  alignText;      // text alignment for short messages: ALIGN_LEFT / CENTER / RIGHT
  char     hostname[32];   // OTA + MQTT client hostname (max 31 chars + null)
  char     mqttServer[40]; // MQTT broker IP or hostname (max 39 chars + null)
  uint16_t mqttPort;       // MQTT broker port (default 1883)
};

// ─── Per-architecture SPI pin defaults ───────────────────────────────────────
// All values are GPIO numbers (not Arduino D-pin aliases) so they compile on
// every supported target.  Override via MQTT after first boot if your wiring
// differs from the defaults below.
//
//  Board / module           CLK        MOSI       CS
//  ──────────────────────  ────────   ────────   ────────
//  ESP8266 (D1 Mini         14 (D5)    13 (D7)    12 (D6)
//  ESP32 DevKit             18         23          5
//  ESP32-S2 Saola-1         36         35         34
//  ESP32-C3 XIAO / DevKit    6          7         20
#if defined(ARDUINO_ARCH_ESP8266)
  #define DEFAULT_PIN_CLK   14     // D5
  #define DEFAULT_PIN_DATA  13     // D7
  #define DEFAULT_PIN_CS    12     // D6
  #define DEFAULT_PIN_AUX    3     // GPIO3 = D0 on D1 Mini / NodeMCU
  #define DEFAULT_PIN_HB_LED 2     // GPIO2 = D4, onboard LED on most ESP8266 boards
#elif defined(CONFIG_IDF_TARGET_ESP32S2)
  #define DEFAULT_PIN_CLK   36     // 
  #define DEFAULT_PIN_DATA  35     // 
  #define DEFAULT_PIN_CS    34     // 
  #define DEFAULT_PIN_AUX    1     // GPIO1 — free on most ESP32-S2 boards
  #define DEFAULT_PIN_HB_LED 2     // onboard LED on Saola-1 / FeatherS2
#elif defined(CONFIG_IDF_TARGET_ESP32C3)
  #define DEFAULT_PIN_CLK    6     // 
  #define DEFAULT_PIN_DATA   7     // 
  #define DEFAULT_PIN_CS    20     // 
  #define DEFAULT_PIN_AUX    1     // GPIO1 — free on XIAO C3
  #define DEFAULT_PIN_HB_LED 8     // onboard WS2812 data pin on XIAO C3 (use a plain GPIO for a simple LED)
#elif defined(ARDUINO_ARCH_ESP32)  // plain ESP32 — must come after S2/C3
  #define DEFAULT_PIN_CLK   18     // 
  #define DEFAULT_PIN_DATA  23     // 
  #define DEFAULT_PIN_CS     5     // 
  #define DEFAULT_PIN_AUX    1     // GPIO1 (TX) — repurpose only if Serial is unused
  #define DEFAULT_PIN_HB_LED 2     // onboard LED on most ESP32 DevKit boards
#else
  #error "No default SPI pins defined for this target — add them above."
#endif

// ─── Other tuneable defaults ─────────────────────────────────────────────────
#define DEFAULT_HW_TYPE      ((uint8_t)MD_MAX72XX::FC16_HW)
#define DEFAULT_NUM_DEVICES  4             // 1–8; each MAX7219 drives 8 columns, so 4 = 32 columns total
#define DEFAULT_SCROLL_DELAY 100           // ms — lower = faster scroll
#define DEFAULT_INTENSITY    5             // 0 (off) … 15 (max)
#define DEFAULT_HOSTNAME     "LED_MATRIX"  // default hostname for OTA + MQTT (max 31 chars)
#define DEFAULT_MQTT_SERVER  ""            // blank — forces portal entry on first boot
#define DEFAULT_MQTT_PORT    1883          // default MQTT port

// ─── Animation modes ──────────────────────────────────────────────────────────
// Sent as integer over MQTT topic /<hostname>/anim
//
//  Value  Name              Description
//  ────────────────────────────────────────────────────────────────────────────
//  0   SCROLL_LEFT      Continuous scroll right→left            (default)
//  1   SCROLL_RIGHT     Continuous scroll left→right
//  2   SCROLL_UP        Continuous scroll downward→up
//  3   SCROLL_DOWN      Continuous scroll upward→down
//  4   FLIP_LR          Static display, mirrored left↔right
//  5   FLIP_UD          Static display, mirrored top↔bottom
//  6   ROTATE_CW        Rotate display 90° clockwise each tick
//  7   INVERT           Invert all pixels (dark↔light) each tick
//  8   BOUNCE           Scroll left until end, then reverse right (ping-pong)
//  9   SCROLL_LEFT_INV  Scroll left with pixels inverted
//  10  BLINK            Whole display blinks at scroll speed
//  11  WIPE_IN_LR       Wipe columns in from both sides toward centre
//  12  WIPE_OUT_LR      Wipe columns out from centre toward both sides
//
// pauseMs (MQTT topic /<hostname>/pause, 0 = disabled):
//   After each full message pass, hold the display for pauseMs milliseconds
//   before starting the next pass.  Works with all scroll modes.
#define ANIM_SCROLL_LEFT     0
#define ANIM_SCROLL_RIGHT    1
#define ANIM_SCROLL_UP       2
#define ANIM_SCROLL_DOWN     3
#define ANIM_FLIP_LR         4
#define ANIM_FLIP_UD         5
#define ANIM_ROTATE_CW       6
#define ANIM_INVERT          7
#define ANIM_BOUNCE          8
#define ANIM_SCROLL_LEFT_INV 9
#define ANIM_BLINK           10
#define ANIM_WIPE_IN         11
#define ANIM_WIPE_OUT        12
#define ANIM_MODE_MAX        12       // 

#define DEFAULT_ANIM_MODE  ANIM_SCROLL_LEFT
#define DEFAULT_PAUSE_MS    0         // 0 = no pause between passes

// Text alignment for short messages (rendered width ≤ display width).
// Sent as integer over MQTT topic /<hostname>/align
#define ALIGN_LEFT   0   // Flush left  (default)
#define ALIGN_CENTER 1   // Horizontally centred
#define ALIGN_RIGHT  2   // Flush right
#define ALIGN_MAX    2

#define DEFAULT_ALIGN_TEXT ALIGN_LEFT

// ─── Runtime config (loaded from EEPROM; falls back to defaults on first boot)
// Plain aggregate initialisation is used here — C99 designated initialisers
// (.field = value) are a GCC extension that the ESP toolchain rejects in C++.
MatrixConfig cfg = {
  EEPROM_MAGIC,          // magic
  DEFAULT_HW_TYPE,       // hwType
  DEFAULT_NUM_DEVICES,   // numDevices
  DEFAULT_PIN_CLK,       // clkPin
  DEFAULT_PIN_DATA,      // dataPin
  DEFAULT_PIN_CS,        // csPin
  DEFAULT_PIN_AUX,       // auxPin
  DEFAULT_PIN_HB_LED,    // hbLedPin
  DEFAULT_SCROLL_DELAY,  // scrollDelay
  DEFAULT_INTENSITY,     // intensity
  DEFAULT_ANIM_MODE,     // animMode
  DEFAULT_PAUSE_MS,      // pauseMs
  DEFAULT_ALIGN_TEXT,    // alignText
  DEFAULT_HOSTNAME,      // hostname
  DEFAULT_MQTT_SERVER,   // mqttServer
  DEFAULT_MQTT_PORT      // mqttPort
};

// ─── MQTT Topics (built dynamically from cfg.hostname) ───────────────────────
// Topic pattern:  /<hostname>/<suffix>
// e.g. hostname "LOBBY" → "/LOBBY/value", "/LOBBY/config/hwtype", etc.
//
// The hostname config topic is always fixed to "matrix/config/hostname"
// so any device can be renamed regardless of its current hostname.
#define TOPIC_MAX 80  // enough for "homeassistant/number/<31-char-hostname>/speed/config\0"

struct Topics {
  char pup_alive        [TOPIC_MAX];  // Published with retain=true on startup to signal presence; retained until power off
  char sub_value        [TOPIC_MAX];  // Subscribes to new message text
  char sub_speed        [TOPIC_MAX];  // Scroll speed (ms between steps)
  char sub_intensity    [TOPIC_MAX];  // Display intensity (0–15)
  char sub_OnOff        [TOPIC_MAX];  // Display on/off (true/false)
  char sub_anim         [TOPIC_MAX];  // Animation mode
  char sub_pause        [TOPIC_MAX];  // Pause duration between passes (ms)
  char sub_align        [TOPIC_MAX];  // Text alignment: 0=left 1=center 2=right
  char sub_cfg_hwtype   [TOPIC_MAX];  // Hardware type (MD_MAX72XX::moduleType_t cast to uint8_t)
  char sub_cfg_numdev   [TOPIC_MAX];  // Number of chained devices
  char sub_cfg_clkpin   [TOPIC_MAX];  // Clock pin
  char sub_cfg_datapin  [TOPIC_MAX];  // Data pin
  char sub_cfg_cspin    [TOPIC_MAX];  // Chip select pin
  char sub_cfg_auxpin   [TOPIC_MAX];  // Auxiliary output pin (e.g. for LDR control)
  char sub_cfg_hbledpin [TOPIC_MAX];  // Heartbeat LED pin
  char pub_cfg_status   [TOPIC_MAX];  // Publishes current config as JSON to this topic on every change
  char sub_cfg_hostname [TOPIC_MAX];  // Fixed — always "matrix/config/hostname"

  // Home Assistant MQTT discovery topics (publish with retain=true)
  // Pattern: homeassistant/<component>/<hostname>/<object>/config
  char ha_text     [TOPIC_MAX];       // Text entity   — message input
  char ha_light    [TOPIC_MAX];       // Light entity  — on/off + brightness
  char ha_speed    [TOPIC_MAX];       // Number entity — scroll speed
  char ha_pause    [TOPIC_MAX];       // Number entity — pause between passes
  char ha_anim     [TOPIC_MAX];       // Select entity — animation mode
  char ha_align    [TOPIC_MAX];       // Select entity — text alignment
} t;

// Call after eepromLoad() and after every hostname change.
void buildTopics() {
  const char* h = cfg.hostname;
  snprintf(t.pup_alive,        TOPIC_MAX, "%s/active",             h);
  snprintf(t.sub_value,        TOPIC_MAX, "%s/value",              h);
  snprintf(t.sub_speed,        TOPIC_MAX, "%s/speed",              h);
  snprintf(t.sub_intensity,    TOPIC_MAX, "%s/intensity",          h);
  snprintf(t.sub_OnOff,        TOPIC_MAX, "%s/state",              h);
  snprintf(t.sub_anim,         TOPIC_MAX, "%s/anim",               h);
  snprintf(t.sub_pause,        TOPIC_MAX, "%s/pause",              h);
  snprintf(t.sub_align,        TOPIC_MAX, "%s/align",              h);
  snprintf(t.sub_cfg_hwtype,   TOPIC_MAX, "%s/config/hwtype",      h);
  snprintf(t.sub_cfg_numdev,   TOPIC_MAX, "%s/config/numdevices",  h);
  snprintf(t.sub_cfg_clkpin,   TOPIC_MAX, "%s/config/clkpin",      h);
  snprintf(t.sub_cfg_datapin,  TOPIC_MAX, "%s/config/datapin",     h);
  snprintf(t.sub_cfg_cspin,    TOPIC_MAX, "%s/config/cspin",       h);
  snprintf(t.sub_cfg_auxpin,   TOPIC_MAX, "%s/config/auxpin",      h);
  snprintf(t.sub_cfg_hbledpin, TOPIC_MAX, "%s/config/hbledpin",    h);
  snprintf(t.pub_cfg_status,   TOPIC_MAX, "%s/config/status",      h);
  // Fixed rename topic — literal "matrix" prefix so every device can be
  // targeted for renaming before its hostname is known.
  strncpy(t.sub_cfg_hostname, "matrix/config/hostname", TOPIC_MAX - 1);
  t.sub_cfg_hostname[TOPIC_MAX - 1] = '\0';

  // Home Assistant (HA) discovery topics — 64 chars is tight;
  // HA prefix + component + hostname + object + /config
  // Use a longer local buffer here since TOPIC_MAX is for runtime topics only.
  snprintf(t.ha_text,  TOPIC_MAX, "homeassistant/text/%s/message/config",   h);
  snprintf(t.ha_light, TOPIC_MAX, "homeassistant/light/%s/display/config",  h);
  snprintf(t.ha_speed, TOPIC_MAX, "homeassistant/number/%s/speed/config",   h);
  snprintf(t.ha_pause, TOPIC_MAX, "homeassistant/number/%s/pause/config",   h);
  snprintf(t.ha_anim,  TOPIC_MAX, "homeassistant/select/%s/anim/config",    h);
  snprintf(t.ha_align, TOPIC_MAX, "homeassistant/select/%s/align/config",   h);

  Serial.printf("Topics built for hostname: %s\n", h);
}

// ─── Runtime State ───────────────────────────────────────────────────────────
#define OFF false
#define ON  true

bool   matrix_state         = true;
bool   intensity_update     = false;
bool   hardware_reconfigure = false;   // Set true when a config topic arrives
bool   firstConnect         = true;    // Show "WiFi+MQTT OK" on first MQTT connect only
bool   passComplete         = false;   // Set by scrollDataSource at end of each message pass
bool   scrollReset          = false;   // Set to force scrollDataSource back to S_IDLE cleanly

const uint8_t MESG_SIZE    = 255;
const uint8_t CHAR_SPACING = 1;

char curMessage[MESG_SIZE];
char newMessage[MESG_SIZE];
bool newMessageAvailable    = false;

long clearTimer = 0;

// ─── Forward declarations ────────────────────────────────────────────────────
// Required because matrixInit() registers these callbacks before their
// definitions appear later in the file.
void    scrollDataSink(uint8_t dev, MD_MAX72XX::transformType_t t, uint8_t col);
uint8_t scrollDataSource(uint8_t dev, MD_MAX72XX::transformType_t t);

// ─── Hardware Objects (rebuilt on reconfigure) ───────────────────────────────
MD_MAX72XX* mx = nullptr;   // Heap-allocated so we can delete/recreate it

WiFiClient   espClient;
PubSubClient client(espClient);

// ─── EEPROM helpers ──────────────────────────────────────────────────────────
void eepromLoad() {
  EEPROM.begin(EEPROM_SIZE);
  MatrixConfig tmp;
  EEPROM.get(0, tmp);
  if (tmp.magic == EEPROM_MAGIC) {
    cfg = tmp;
    Serial.println(F("Config loaded from EEPROM."));
  } else {
    Serial.println(F("No valid EEPROM config – using defaults."));
  }
  EEPROM.end();
}

void eepromSave() {
  EEPROM.begin(EEPROM_SIZE);
  cfg.magic = EEPROM_MAGIC;
  EEPROM.put(0, cfg);
  EEPROM.commit();
  EEPROM.end();
  Serial.println(F("Config saved to EEPROM."));
}

// ─── Matrix (re)initialisation ───────────────────────────────────────────────
void matrixInit() {
  if (mx) {
    mx->clear();
    delete mx;
    mx = nullptr;
  }

  // MD_MAX72XX does not expose a destructor that releases the SPI bus on
  // ESP8266, but re-constructing with the same pins is safe here.
  mx = new MD_MAX72XX(
    (MD_MAX72XX::moduleType_t)cfg.hwType,
    cfg.csPin,          // SW SPI: use HW SPI constructor (CS only)
    cfg.numDevices
  );

  mx->begin();
  mx->setShiftDataInCallback(scrollDataSource);
  mx->setShiftDataOutCallback(scrollDataSink);
  mx->control(MD_MAX72XX::INTENSITY, cfg.intensity);

  curMessage[0] = newMessage[0] = '\0';
  Serial.printf("Matrix init: hwType=%d devices=%d CS=%d\n",
                cfg.hwType, cfg.numDevices, cfg.csPin);
}

// ─── Swedish glyph table ──────────────────────────────────────────────────────
// MD_MAX72XX has no runtime API to inject bitmaps for arbitrary codepoints.
// Instead we intercept getChar() calls for the six Latin-1 Swedish codepoints
// and return our own 5-column bitmaps directly.
//
// Column bitmaps are 8 bits tall, LSB = top row, stored left→right.
// Designed at 5 columns wide to match the default font proportions.
//
//  å 0xE5   ä 0xE4   ö 0xF6   Å 0xC5   Ä 0xC4   Ö 0xD6   ° 0xB0
struct SwedishGlyph { uint8_t code; uint8_t cols[5]; };
static const SwedishGlyph swedishGlyphs[] PROGMEM = {
  // å — base 'a' (0x20,0x54,0x54,0x54,0x78) + small ring in rows 0-1 above
  //     ring: outer cols get bit1, inner cols get bit0
  { 0xE5, { 0x22, 0x55, 0x55, 0x56, 0x78 } },
  // ä — base 'a' + diaeresis dots (bit1) at cols 1 and 3
  { 0xE4, { 0x20, 0x56, 0x54, 0x56, 0x78 } },
  // ö — base 'o' (0x38,0x44,0x44,0x44,0x38) + diaeresis dots (bit1) at cols 1 and 3
  { 0xF6, { 0x38, 0x46, 0x44, 0x46, 0x38 } },
  // Å — capital 'A' with ring above
  { 0xC5, { 0x7C, 0x12, 0x11, 0x12, 0x7C } },
  // Ä — capital 'A' with diaeresis
  { 0xC4, { 0x7D, 0x12, 0x11, 0x12, 0x7D } },
  // Ö — capital 'O' with diaeresis
  { 0xD6, { 0x39, 0x44, 0x44, 0x44, 0x39 } },
  // ° — degree sign: small circle in top of cell
  //     col pattern: .XX. / X..X / X..X / .XX. / ....
  //     bits (LSB=top row): 0x06=00000110, 0x09=00001001
  { 0xB0, { 0x06, 0x09, 0x09, 0x06, 0x00 } },
};
static const uint8_t SWEDISH_GLYPH_COUNT =
  sizeof(swedishGlyphs) / sizeof(swedishGlyphs[0]);

// Drop-in replacement for mx->getChar().
// Checks the Swedish table first; falls through to the library font otherwise.
uint8_t getCharBitmap(uint8_t c, uint8_t size, uint8_t* buf) {
  for (uint8_t i = 0; i < SWEDISH_GLYPH_COUNT; i++) {
    if (pgm_read_byte(&swedishGlyphs[i].code) == c) {
      uint8_t w = min((uint8_t)5, size);
      for (uint8_t j = 0; j < w; j++)
        buf[j] = pgm_read_byte(&swedishGlyphs[i].cols[j]);
      return w;
    }
  }
  return mx->getChar(c, size, buf);
}

// ─── OTA ─────────────────────────────────────────────────────────────────────
void OTA_setup() {
  ArduinoOTA.setPort(8266);
  ArduinoOTA.setHostname(cfg.hostname);   // set from persisted config
  ArduinoOTA.setPassword("admin");
  ArduinoOTA.onStart([]()  { Serial.println("OTA Start"); });
  ArduinoOTA.onEnd([]()    { Serial.println("\nOTA End"); });
  ArduinoOTA.onProgress([](unsigned int p, unsigned int t) {
    Serial.printf("OTA Progress: %u%%\r", p / (t / 100));
  });
  ArduinoOTA.onError([](ota_error_t e) {
    Serial.printf("OTA Error[%u]: ", e);
    if      (e == OTA_AUTH_ERROR)    Serial.println("Auth Failed");
    else if (e == OTA_BEGIN_ERROR)   Serial.println("Begin Failed");
    else if (e == OTA_CONNECT_ERROR) Serial.println("Connect Failed");
    else if (e == OTA_RECEIVE_ERROR) Serial.println("Receive Failed");
    else if (e == OTA_END_ERROR)     Serial.println("End Failed");
  });
  ArduinoOTA.begin();
  Serial.print(F("OTA ready – IP: "));
  Serial.println(WiFi.localIP());
}

// ─── Scroll callbacks ────────────────────────────────────────────────────────
void scrollDataSink(uint8_t dev, MD_MAX72XX::transformType_t t, uint8_t col) {
#if PRINT_CALLBACK
  Serial.printf("\ncb dev=%d t=%d col=%d", dev, t, col);
#endif
}
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
void loop() {
  if (!client.connected()) reconnect();
  client.loop();

  ArduinoOTA.handle();

  // Hardware/hostname reconfigure deferred from MQTT callback to loop() to
  // avoid running on the PubSubClient stack.
  if (hardware_reconfigure) {
    hardware_reconfigure = false;

    // Save whatever was on screen so we can restore it after the notification
    char savedMessage[MESG_SIZE];
    strncpy(savedMessage, curMessage, MESG_SIZE - 1);
    savedMessage[MESG_SIZE - 1] = '\0';

    buildTopics();
    client.disconnect();
    matrixInit();

    // Show "reconfigured!" once, then restore the previous message
    strcpy(curMessage, "reconfigured!");
    strcpy(newMessage, savedMessage);
    newMessageAvailable = true;

    // Reset scroll state so "reconfigured!" starts cleanly
    scrollReset  = false;
    passComplete = false;
    staticShown  = false;
    pausing      = false;
  }

  if (intensity_update) {
    intensity_update = false;
    mx->control(MD_MAX72XX::INTENSITY, cfg.intensity);
  }

#if LED_HEARTBEAT
  static uint32_t timeLast = 0;
  if (millis() - timeLast >= HB_LED_TIME) {
    digitalWrite(cfg.hbLedPin, digitalRead(cfg.hbLedPin) == LOW ? HIGH : LOW);
    timeLast = millis();
  }
#endif

  scrollText();
}

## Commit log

2023-06-09 PCB for Wemos D1 Mini and Wemos S2 Mini
    PCB for MAX7219 made in Eagle (But I will change to KiCAD due to the changes in Eagle that Autodesk is doing).
    [Wemos-ESP32_MAX7219 v1.brd, Wemos-ESP32_MAX7219 v1.sch, Wemos-ESP8266_MAX7219 v5.brd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]
2023-06-09 Hardware designs
    Made in Eagle PCB CAD
2023-06-09 Minor corrections
    [Wemos-ESP32_MAX7219 v1.brd, Wemos-ESP8266_MAX7219 v5.sch]
2026-03-07 Enhance README with MQTT and configuration details
    Expanded the README.md to include detailed MQTT topic references, usage examples, and hardware configuration topics for the LED_MATRIX project.
2026-03-22 Add IP address publishing for OTA updates via MQTT
    Publish the device's IP address for easier OTA targeting.
